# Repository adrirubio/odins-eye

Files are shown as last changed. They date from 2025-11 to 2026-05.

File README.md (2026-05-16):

# Odin's Eye

**Full Design Process**: [Blueprint Project](https://blueprint.hackclub.com/projects/413)

A compact speed detection system using a Raspberry Pi and a TF-Luna LiDAR sensor monitors vehicles in real time. When a vehicle is detected passing by, the system measures its speed and triggers the Raspberry Pi Camera Module 3 to capture an image.

Captured images are processed locally on a Raspberry Pi Zero 2 W, where the system identifies the vehicle and, when applicable, extracts license plate information. With built-in Wi-Fi connectivity, the unit wirelessly transmits speed data and image results directly to your phone. The entire system is designed to operate autonomously, combining precise sensing, on-device image analysis, and seamless wireless communication in a compact DIY build.

## Features

- **Vehicle Speed Detection:** Real-time speed measurement using a TF-Luna LiDAR sensor
- **Automatic Photo Capture:** Raspberry Pi Camera Module 3 captures an image when a vehicle passes
- **On-Device Processing:** Raspberry Pi Zero 2 W analyzes captured images locally
- **Vehicle Recognition:** Detects vehicles within the captured image
- **License Plate Detection:** Extracts license plate information when a car is detected
- **Wireless Notifications:** Sends captured data and images directly to your phone over WiFi
- **OLED Display:** Shows detected speed and system status directly on the device
- **Autonomous Operation:** Runs continuously without manual interaction
- **Compact DIY Design:** Designed as a small, self-contained monitoring system

## Hardware/BOM

| Component | Qty | Type |
|---|-----|---|
| Raspberry Pi Zero 2 W | 1 | Controller |
| Raspberry Pi Camera Module 3 | 1 | Camera Module |
| TF-Luna LiDAR Sensor | 1 | LiDAR Sensor |
| 0.95-inch OLED Display | 1 | Display |
| MPU6050 IMU | 1 | Sensor |
| microSD Card (32GB) | 1 | Storage |
| Custom Carrier PCB | 1 | PCB |
| Custom 3D Printed Case | 1 | Enclosure |
| Power Bank | 1 | Power |
| USB-A to USB-C Cable | 1 | Cable |
| Universal Tripod | 1 | Mount |
| Green LED Power Indicator | 1 | Indicator |
| Mounting Hardware (Assorted Screws) | 1 | Hardware |

## CAD Screenshots

| CAD Assembly (Front View)| CAD Assembly (Back View) |
|---|---|
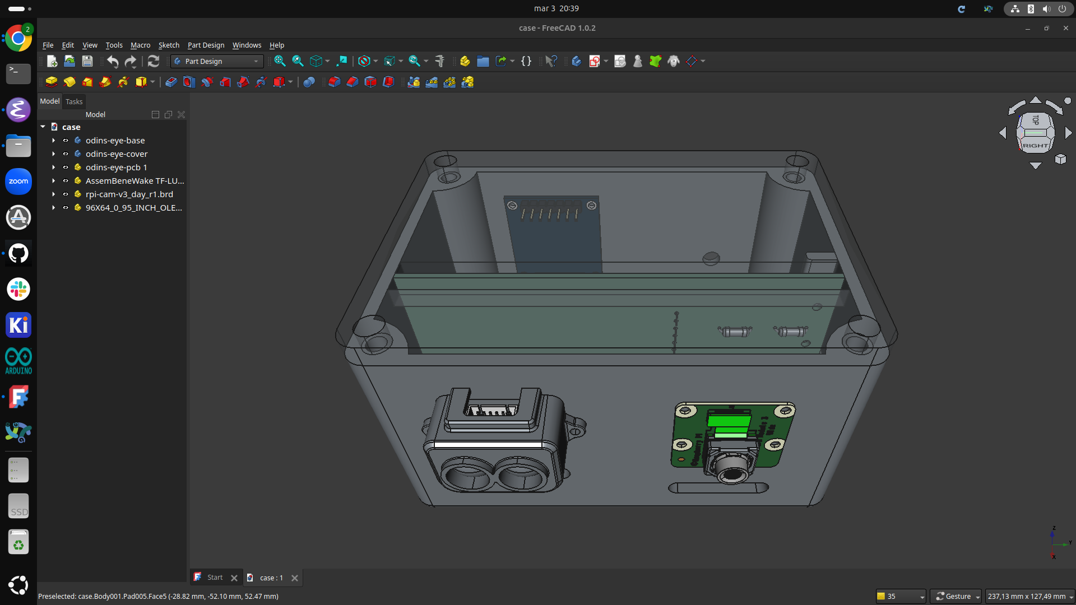
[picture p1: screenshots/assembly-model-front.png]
Assembly Model Front
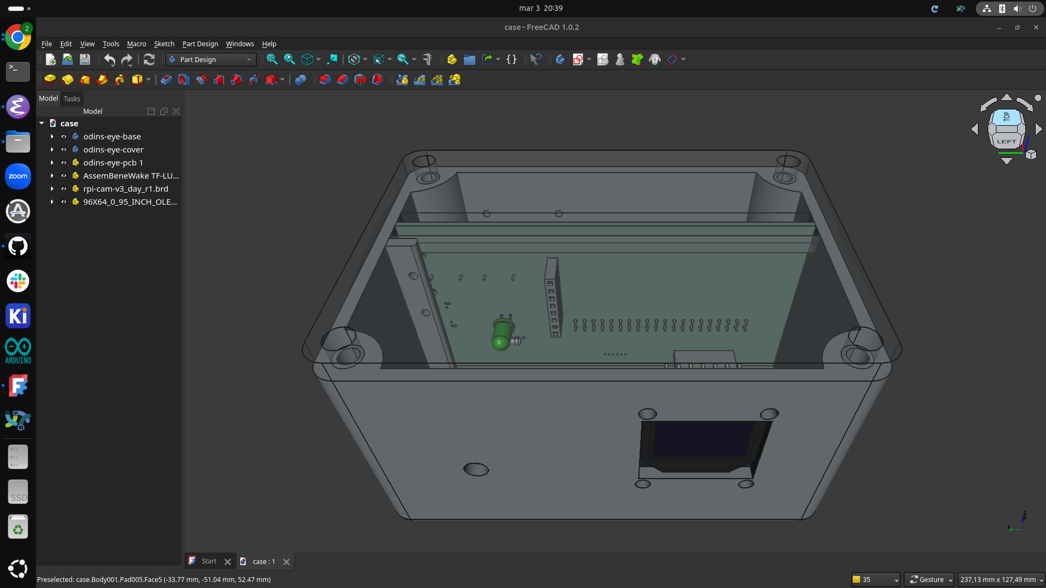
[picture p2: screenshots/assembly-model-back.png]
Assembly Model Back
|  |  |

| 3D Case (Side View) | 3D Case (Side View) |
|---|---|
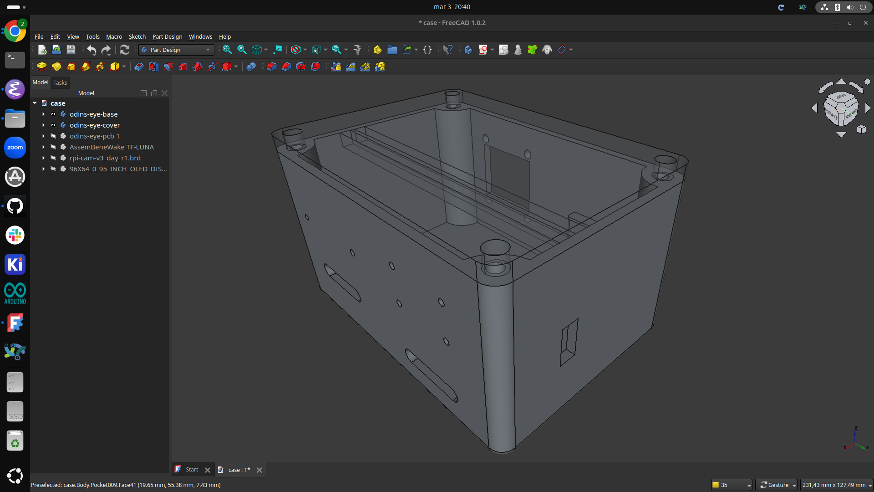
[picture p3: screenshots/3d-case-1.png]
3D Case Side
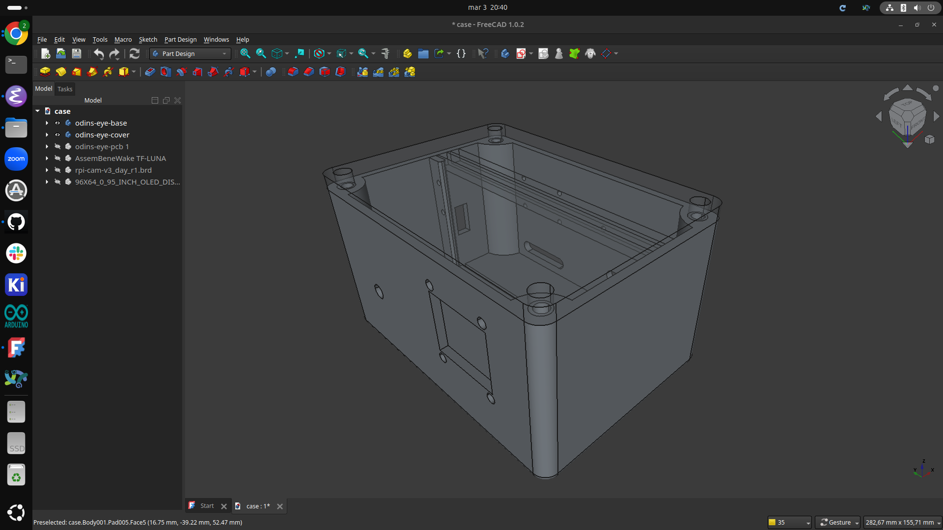
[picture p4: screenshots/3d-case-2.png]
3D Case Side
|  |  |

## PCB Screenshots

| PCB Layout |
|-------------------------------|
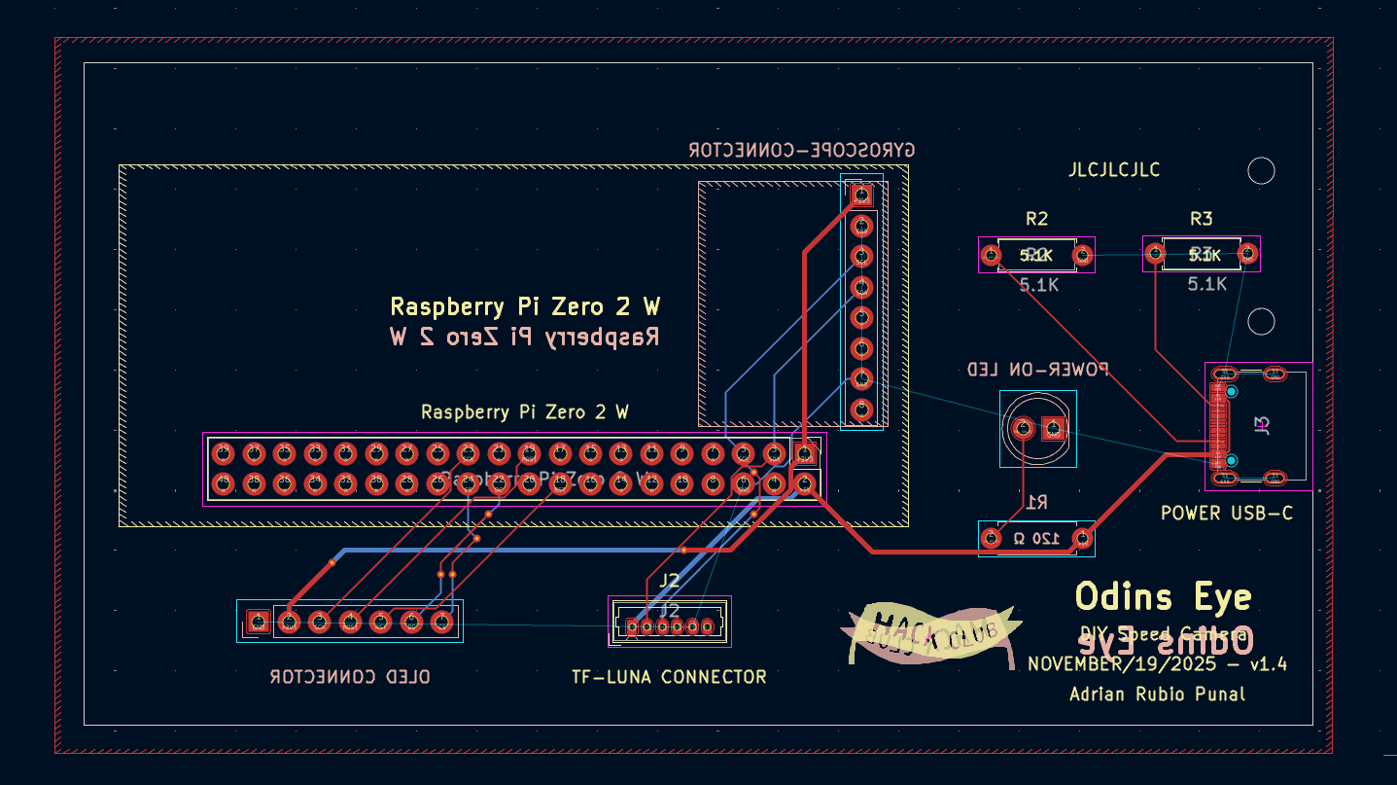
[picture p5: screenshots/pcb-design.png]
PCB Layout
|  |

| PCB 3D View (Front) | PCB 3D View (Back) |
|---|---|
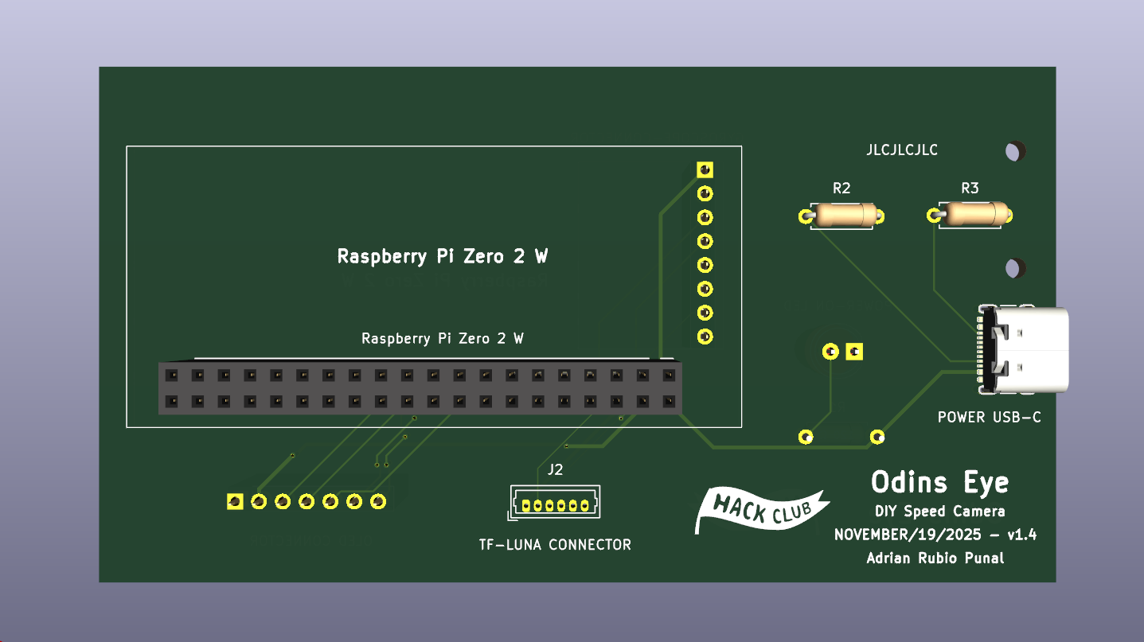
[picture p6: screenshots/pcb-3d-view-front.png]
PCB 3D View (Front)
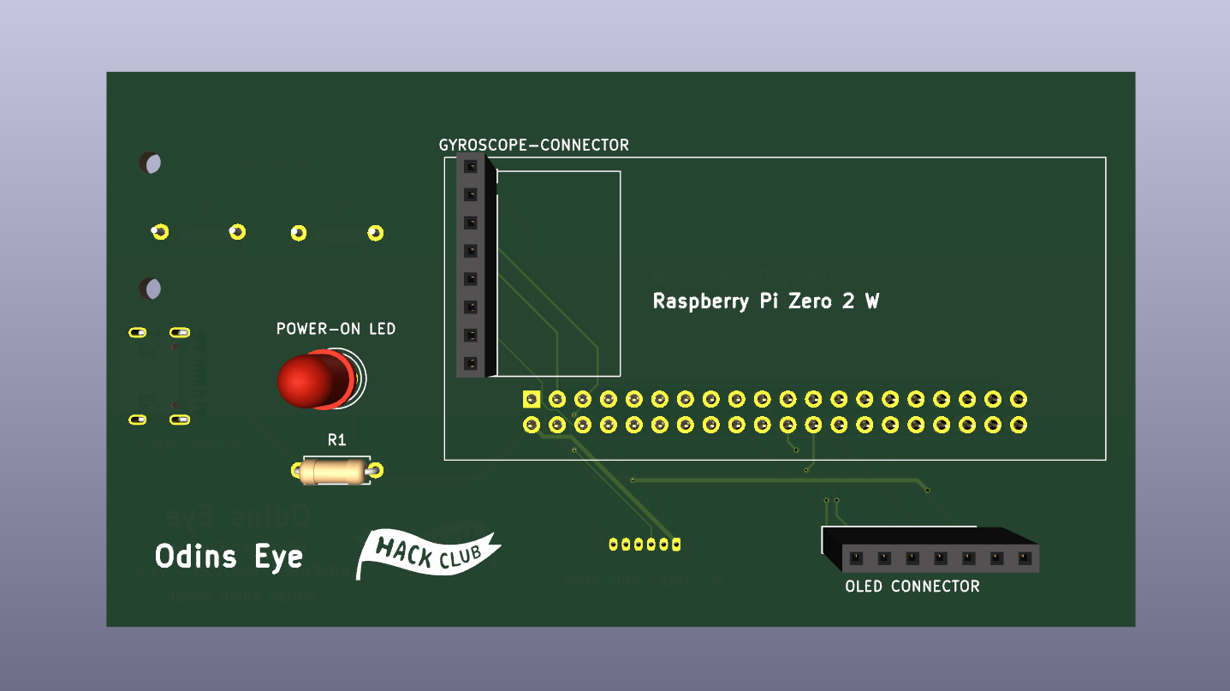
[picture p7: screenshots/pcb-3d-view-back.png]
PCB 3D View (Back)
|  |  |

## Usage
Place the system facing the road and use the built-in gyroscope to help align the device at the correct angle for accurate measurements. The TF-Luna LiDAR sensor detects passing vehicles and calculates their speed, triggering the camera to capture an image as a vehicle passes. The Raspberry Pi then processes the image to detect the vehicle and extract the license plate if possible, sending the results to your phone over WiFi. The detected speed and system status are also displayed on the integrated OLED screen, allowing you to quickly view results directly on the device.

## Odins Eye In Action

| Complete Assembly |
|-------------------------------|
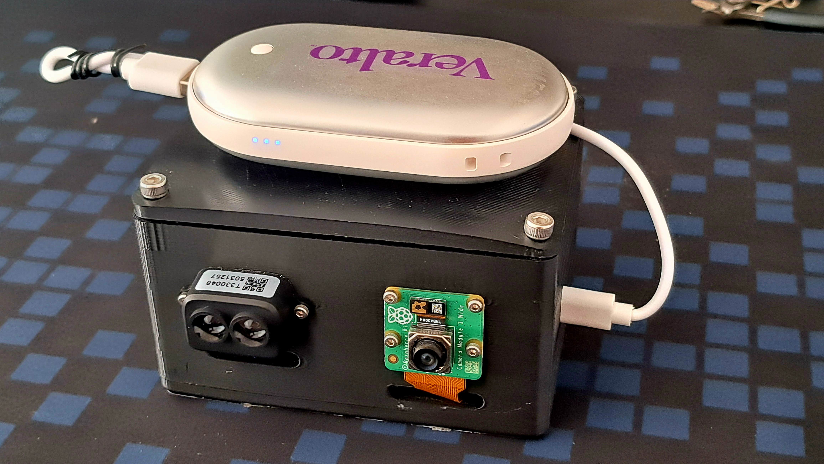
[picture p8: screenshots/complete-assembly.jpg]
Complete Assembly
|  |

| Complete Assembly (Front View)| Complete Assembly (Front View) |
|---|---|
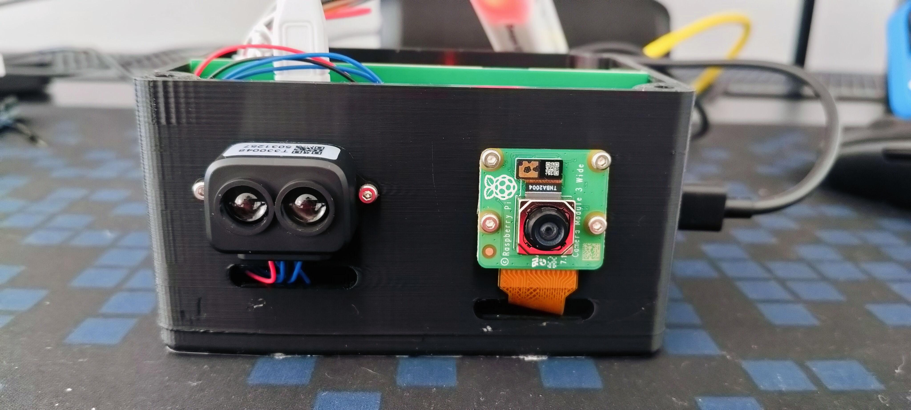
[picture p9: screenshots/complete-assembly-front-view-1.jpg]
Complete Assembly Front View
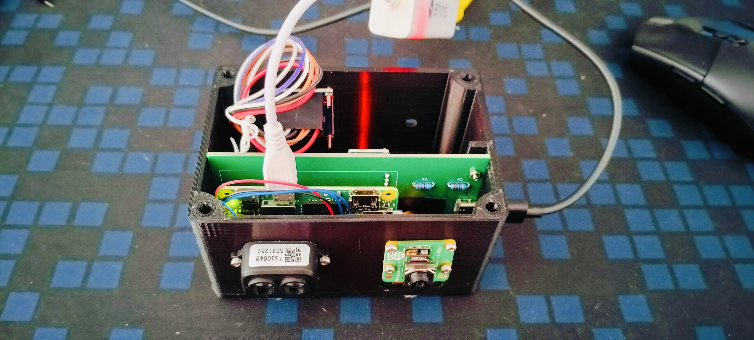
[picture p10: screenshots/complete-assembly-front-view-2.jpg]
Complete Assembly Front View
|  |  |

| Complete Assembly (Top View)| Complete Assembly (Side View) |
|---|---|
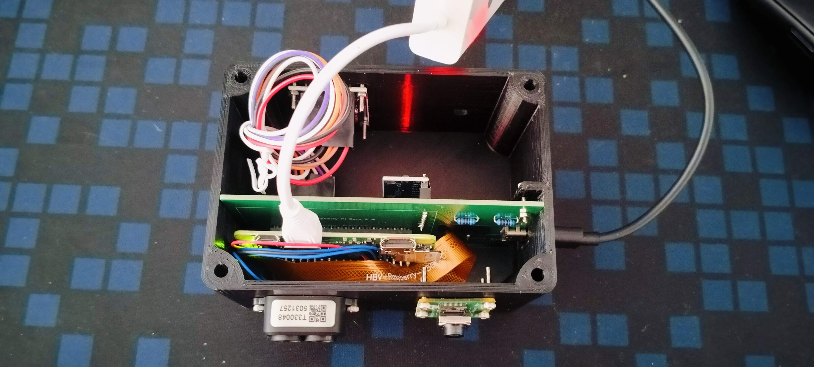
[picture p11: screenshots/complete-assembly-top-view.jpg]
Complete Assembly Top View
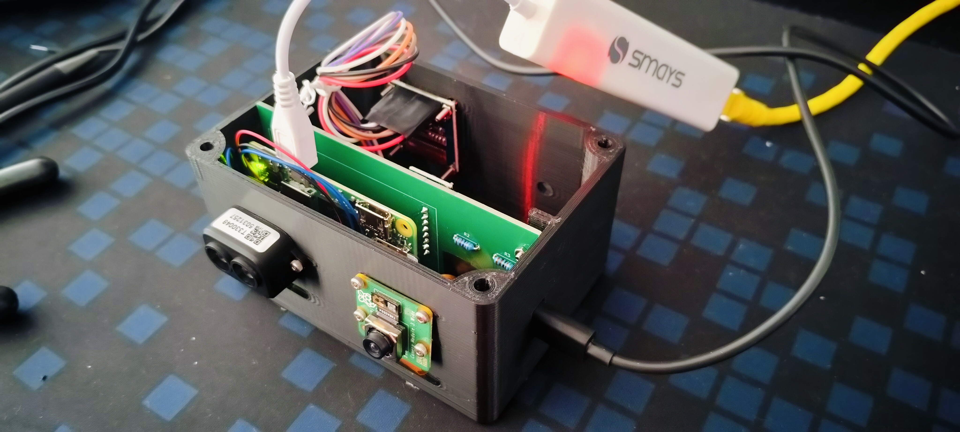
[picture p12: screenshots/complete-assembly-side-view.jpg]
Complete Assembly Side View
|  |  |

| Complete Assembly (Back View)| Complete Assembly (Back View) |
|---|---|
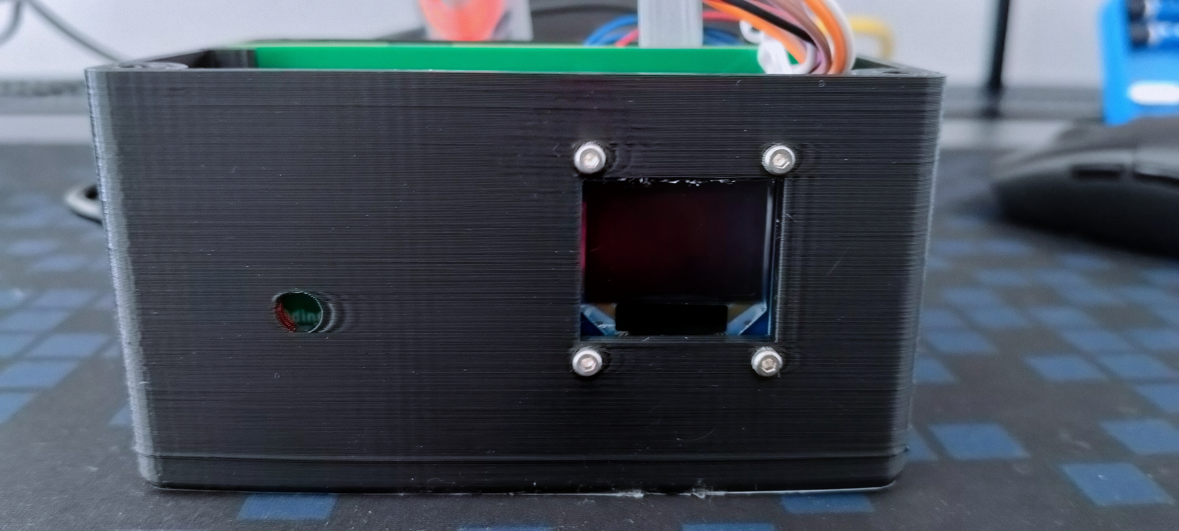
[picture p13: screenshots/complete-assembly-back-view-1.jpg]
Complete Assembly Back View
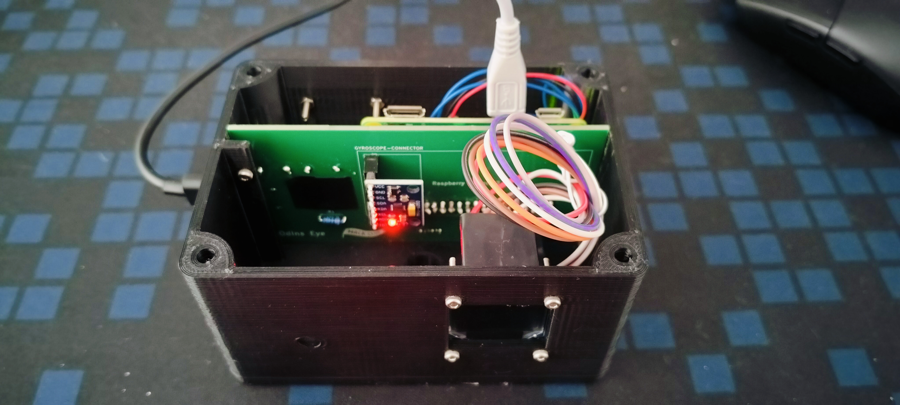
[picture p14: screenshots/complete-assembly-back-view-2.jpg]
Complete Assembly Back View
|  |  |

### Odins Eye Demo
<a href="https://github.com/adrirubio/odins-eye/raw/main/demo/video/odins-eye-demo.mp4">Click here to download the demo video (MP4)</a>

### YouTube Demo
[Watch the demo on YouTube](https://youtu.be/cNV2ZcgS8Qw)

## Running on the Pi

The firmware lives in `firmware/`. Two entry points:

- `odins_eye_speed_monitor.py` — the live detector (TF-Luna sampling, gyro calibration, camera trigger, capture metadata).
- `odins_eye_dashboard_server.py` — a small HTTP server that serves the latest captures at `http://<pi-ip>:8080`.

### One-time setup on the Pi

```bash
sudo apt install python3-pil python3-smbus2 rpicam-apps
git clone https://github.com/adrirubio/odins-eye.git ~/Documents/odins-eye
sudo bash ~/Documents/odins-eye/firmware/systemd/install.sh
```

The install script copies the systemd units into `/etc/systemd/system/`, enables them, and starts both services. After a reboot, both come up automatically.

### Manual run for roadside testing

When you want the gyro calibration prompt and live burst logs in your terminal:

```bash
sudo systemctl stop odins-eye-detector
bash ~/Documents/odins-eye/firmware/odins_eye_start.sh
```

Ctrl-C stops both detector and dashboard. To return to autostart mode:

```bash
sudo systemctl start odins-eye-detector
```

### Useful commands

```bash
systemctl status odins-eye-detector
systemctl status odins-eye-dashboard
journalctl -u odins-eye-detector -f          # live detector log
journalctl -u odins-eye-dashboard -f         # live dashboard log
```

## License

MIT License

---

> GitHub [@adrirubio](https://github.com/adrirubio) &nbsp;&middot;&nbsp;

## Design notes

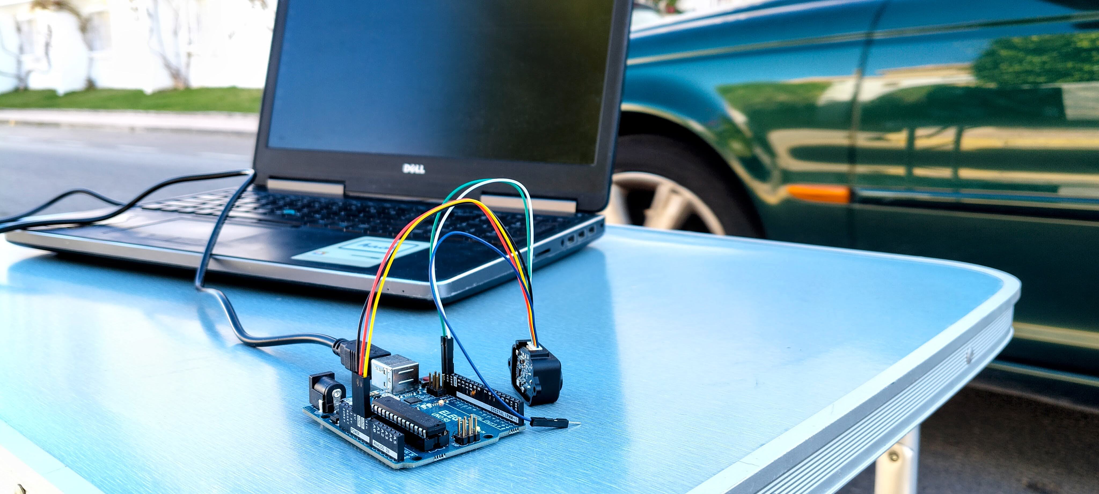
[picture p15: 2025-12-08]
demo/POC-pictures/POC3.jpg

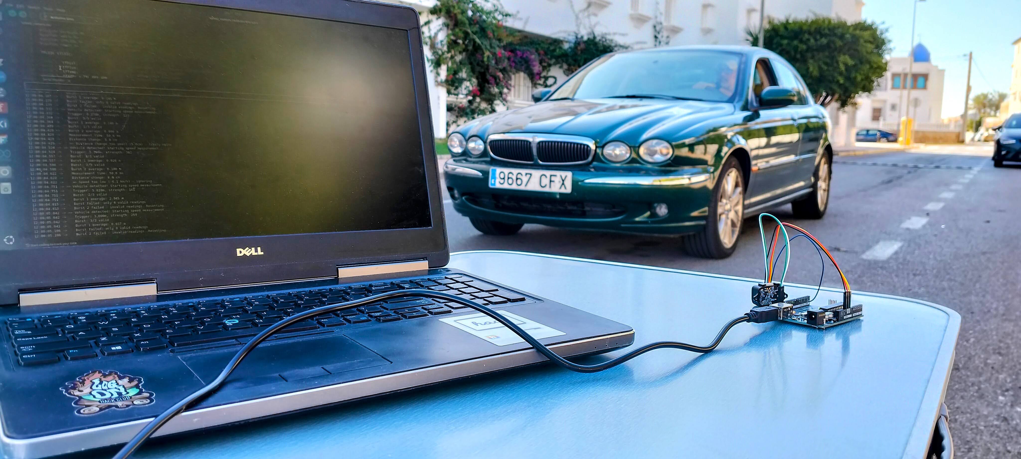
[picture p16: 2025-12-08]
demo/POC-pictures/POC2.jpg

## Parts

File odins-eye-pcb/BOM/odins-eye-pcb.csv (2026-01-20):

Comment | Designator | Footprint | LCSC Part Number
USB Type-C Receptacle, USB 2.0, Right-Angle, Top-Mount, SMT, TH Shell Stakes, 5A 48V | J3 | USB_C_Receptacle_GCT_USB4105-xx-A_16P_TopMnt_Horizontal | C3020560

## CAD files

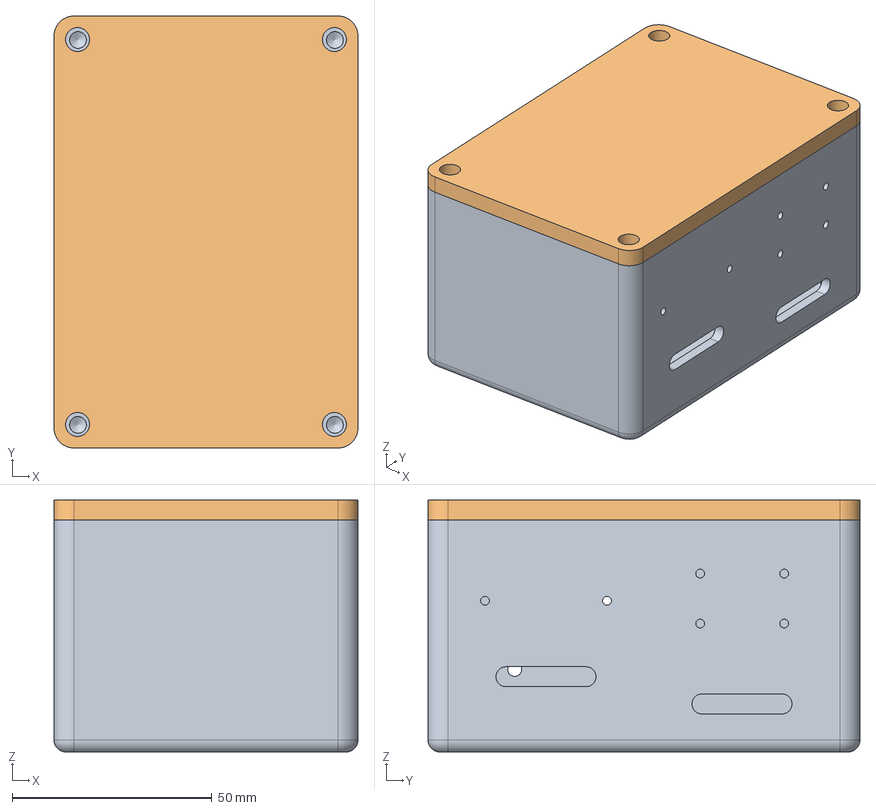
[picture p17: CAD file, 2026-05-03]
odins-eye-case/case.FCStd
76.0 x 108.0 x 63.0 mm
odins-eye-base
odins-eye-cover

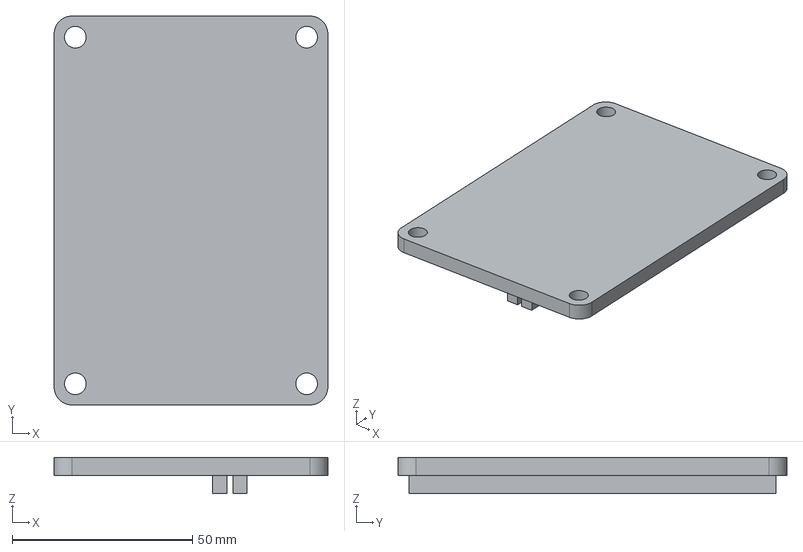
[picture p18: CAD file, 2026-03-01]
odins-eye-case/STEP-files/case-odins-eye-cover.step
76.0 x 108.0 x 10.0 mm

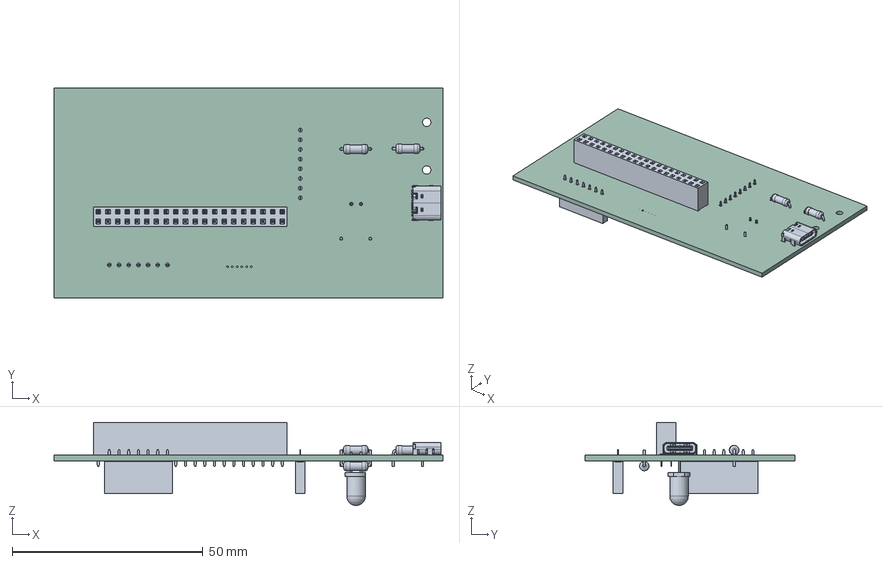
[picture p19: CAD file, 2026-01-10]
odins-eye-pcb/odins-eye-pcb/odins-eye-pcb.step
102.0 x 55.0 x 21.8 mm
USB_C_Receptacle_GCT_USB4105-xx-A_16P_TopMnt_Horizontal
R_Axial_DIN0207_L6.3mm_D2.5mm_P7.62mm_Horizontal x 3
PinSocket_2x20_P2.54mm_Vertical
PinSocket_1x08_P2.54mm_Vertical
LED_D5.0mm
PinSocket_1x07_P2.54mm_Vertical
odins-eye-pcb_PCB

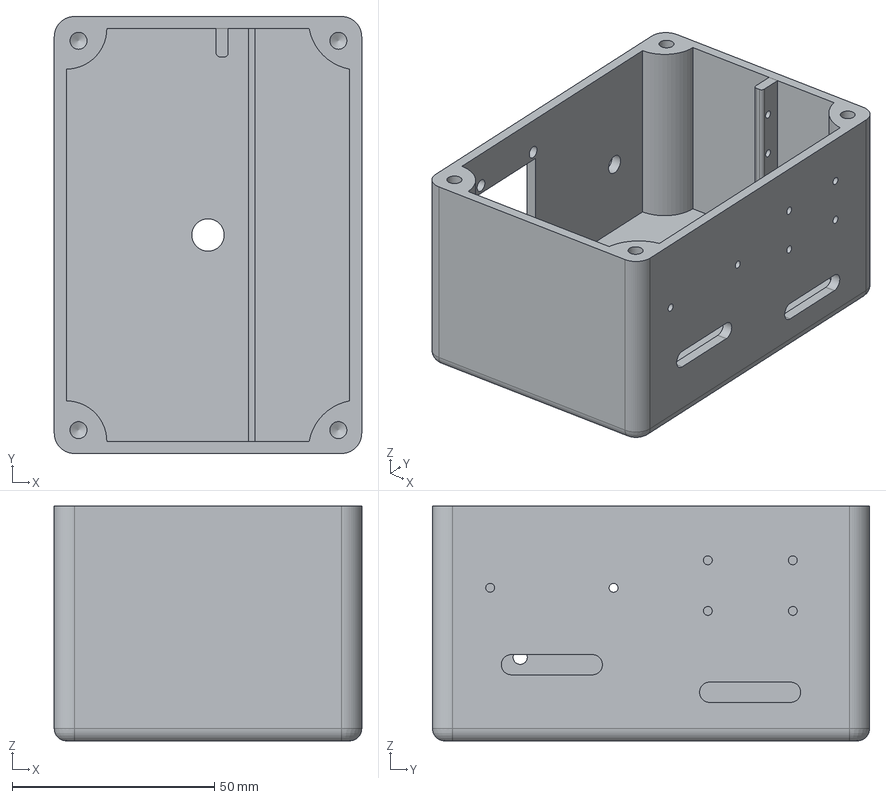
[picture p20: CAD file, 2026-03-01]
odins-eye-case/STEP-files/case-odins-eye-base.step
76.0 x 108.0 x 58.0 mm

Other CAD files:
odins-eye-case/STL-files/enclosure-cover.stl
odins-eye-case/STL-files/enclosure-base.stl

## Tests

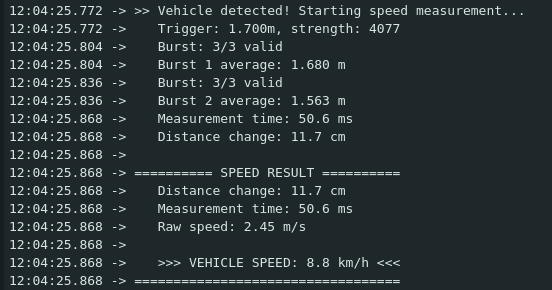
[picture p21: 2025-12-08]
demo/POC-pictures/results.png

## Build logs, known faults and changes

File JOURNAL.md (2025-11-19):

<!--
  ===================    !!READ THIS NOTICE!!   ====================
  DO NOT edit this file manually. Your changes WILL BE OVERWRITTEN!
  This journal is auto generated and updated by Hack Club Blueprint.
  To edit this file, please edit your journal entries on Blueprint.
  ==================================================================
-->

## 10/12/2025 - Research and Project BOM  

I started brainstorming how a DIY speed camera could be possible 3 days ago, and I am quite content with the basic idea I have after a few hours of project and parts research. My original idea was for the speed camera to have a stand that can rotate and follow vehicles while they pass, but I quickly realized that this would overcomplicate the project too much because I would have to design a stand from scratch. I settled for a universal stand where the speed camera and sensor are inside a 3d-printed case that screws onto it. I also wanted a touch screen where you could do some sort of onboarding every time you turned the speed camera on, but this idea was also quickly discarded because the onboarding would be unnecessary and small oled displays usually don't have touch capabilities. I needed the project to be standalone because my idea was for it to be in front of my house and gather data from the passing vehicles. I thought that having a battery holder and a slide switch to turn on was a good idea, but, after talking it over with my dad we decided that it was a better idea to have a power bank that would connect to the pcb/carrier board inside the case through a type-c plug.  

After lots of research and modifying the design several times I ended up with the following base idea that I will build on top of:

The system is controlled by a raspi zero 2w that has a raspi camera module 3, a TF-Luna lidar, and a small, possibly 0,95 inch oled display connected. It works by detecting a vehicle before it passes using the lidar which triggers the camera module 3 to start recording. From the recording it can get the speed using the frames-per-second and distance, it understands using AI what object passed and in the case of it being a car, its license plate. It'll get power from a power bank that can be mounted on top of the 3d-printed case. The lidar and camera will be situated on the front side of the 3d-printed case and on the back will be the oled display and a small green LED that turns on when the pcb/carrier board gets power. Lastly, using the pi's wifi it can send notifications to my phone.

I made the project BOM which you can check out in here: https://github.com/adrirubio/odins-eye/blob/main/bom.csv. I also made some rough sketches with the base idea I have up until now, but none of these are permanent.

Messy Iteration:


Complete Design:


PCB/Carrier Board:
  

## 10/21/2025 - Updated Speed Measurement Method  

I realize that measuring the speed of a vehicle from a video is extremely difficult. There are so many variables that come into play. Now I see how silly my idea was. Here are some of the things that make my original idea so challenging:

- You need to know the real-world distance the car actually travelled
- The video's timing is often unreliable because the frame rate isn't constant
- The camera's angle and lens bend the image

So... I decided to have a long chat with Gemini about other options. I looked into the doppler radar but realized that for it to work I would also need an amplifier, a sperate analog circuit, because the signal would be too weak and noisy for the raspi to read directly. I also looked at the microwave motion sensor but that didn't work because it would detect 360 degrees, so it would also trigger objects moving behind it.

More Messy Iteration:


Then I had a eureka moment; I realized that maybe we could somehow use the TF-Luna lidar to measure the speed of vehicles. Very soon I realized that this could work, here are some reasons why:

- It uses a narrow laser beam, so it will only detect cars passing in front of it
- It's electronically simple, you can connect it directly to the raspi's GPIO pins (via I2C)
- It has very low power consumption and won't put any strain on the power bank (much more efficient than the camera-only method)
- It's extremely fast, at 100Hz, the sensor can check the distance 100 times per second
- It's very compact and it was already in the original design

https://www.amazon.es/-/en/Benewake-TF-Luna-Compatible-Pixhawk-Raspberry/dp/B0DKCSF8C5

Now I would like to briefly explain what a lidar is and what it does. A lidar works by shooting a tiny beam of light and measuring exactly how long it takes for that light to bounce off an object and return.

My first idea on how to get speed was to use the Pythagorean theorem, to use it there would be one fixed distance in the code (a) the perpendicular distance to the side of the road, and we would use the lidar to measure the diagonal distance to the car (c). Using the Pythagorean theorem we would solve for the car's true position along the road (b = sqrt(c^2 - a^2)). By taking two of these measurements in say 0.1 seconds, we could determine the distance the car travelled and divide by the time to find the speed.

The only problem with this method is that it wouldn't be fully drop-and-go because you would have to make sure that (a) is the same in the code as in real life and if not change one of the two. What I am looking for is a completely stand-alone speed camera that starts working without having to be placed at any specific distance.

Knowing this I looked into some other options and found a very promising one; the least squares fit option. In this one the lidar is placed facing the road at roughly 45-degrees angle (I plan on designing a lock on the case). The lidar sends a distance reading every 0.1s until it detects an object in its path, once this happens it starts sending distance readings every 0.001 or 0.005 (I haven't decided yet) and because the object is getting closer at an angle, the distance will decrease as long as the lidar isn't hitting the side of the vehicle. Then it fits a straight line through the readings. The slope of that line tells how fast the distance is shrinking. Because the sensor is tilted, it divides that slope by cos(θ) to get the real speed of the object moving across its view.

To prove this concept, I built some simple example code in python (which I might have to replicate in C++ if speed is a problem) to test the basic idea. I would ask chatgpt to generate a set of distances and the corresponding signal strength and I would test it, honestly I think this might actually work:





Code:
https://github.com/adrirubio/odins-eye/blob/main/firmware/speed-calculation-code.py

To see how this works I bought a TF-Luna lidar to try both of these methods out. It still hasn't arrived but when it does I plan on seeing which of the two speed measurement methods works better and do a proof of concept.  

## 11/5/2025 - Starting The Schematic  

The TF Luna arrived, but because of an ordering mistake, it didn't have the right cables so I couldn't connect it to the breadboard. I could buy the cable separately, but I found one that has all the right cables and is quite cheap, so I decided to buy it. Unfortunately, it will take around two weeks to arrive, so I decided to get started with the schematics.

TF Luna: https://www.amazon.com/Wishiot-TF-Luna-Single-Point-Terminal-WiFi_Lora_32/dp/B09PZ559ZB

This is my first time designing schematics, so to begin with, I looked at some of the guides Blueprint offers. I began by trying EasyEDA. Created an account, started the project, and got a better idea of what components I needed. I started inserting some of the components into EasyEDA. At this point, I needed to get the basics down so I looked at some tutorials. One that helped a lot was this one: https://www.youtube.com/watch?v=R_Ud-FxUw0g

After these tutorials, I thought that I might also have a look at KiCad, so I downloaded it, created the odins-eye project, and having a better idea of what I was doing, I started to get a good feel for it. After following this tutorial for a bit: https://docs.kicad.org/6.0/en/getting_started_in_kicad/getting_started_in_kicad.html, I decided that I was ready to begin designing the speed camera.

The first thing that I looked at was the raspi's 40 GPIO pin header (2x20). Because there wasn't the exact model I needed, and also because I needed to get familiar with KiCad, I decided to design my own. Which I am quite proud of.

Next, I inserted a 6-pin connector which represents the JST connector. I also added the USB-C plug, a 30-pin connector which represents the ZIF connector for the 0.96 oled, one LED with a corresponding resistor, and two more resistors for a voltage divider to measure the battery.

This is where I’m up to so far:

kicad2

## 11/9/2025 - Wiring the Schematic  

I started by laying out the different parts of the project, placing the inputs and power connections on the left, the processing in the middle, and the outputs on the right. This setup made it easier to visualize how data and power would flow through the system. Before wiring the sections, I spent some time researching and watching a few tutorials to make sure I understood everything. I also looked at a few example schematics to double-check pin configurations.

For the plug, I found that I would actually need a USB-C receptacle because I just needed it for charging the circuit. I only connected the necessary power and ground pins and included the proper CC resistors for charging negotiation, then moved on to the 6-pin connector.
The 6-pin connector was fairly easy because, using the pinout diagram from the TF-Luna we had bought, I connected 5V, RXD, TXD, and GND. The last two pins aren't used in this model.

At this point, I connected 5V, GND, RXD, and TXD to pins 2, 6, 8, and 10 respectively on the raspi's GPIO header. I moved on to the 30-pin connector, and here I had some problems. I originally wanted this 30-pin connector because it has no extra PCB border and is great for custom enclosures. The problem is I would have to connect around 20–25 of the 30 pins.

30-pin-connector

I would also have to add capacitors with different values and deal with a large number of pins. This is highly error-prone, and iteration with hardware isn't quick. In the end, I decided to delete the 30-pin connector and use the 7-pin connector, which would represent a header for an OLED like this:
https://www.amazon.es/-/en/HiLetgo-SSD1331-Display-3-3V-5V-Colorful/dp/B0813BB3K7

I wired this 7-pin connector and, lastly, wired the LED, which I decided would be green, using a 1 kΩ resistor. Once everything was wired, I added some no-connect flags on a few unused pins, and a small note on the USB-C. I finished by fixing two or three warnings from the ERC.

schematic2schematic

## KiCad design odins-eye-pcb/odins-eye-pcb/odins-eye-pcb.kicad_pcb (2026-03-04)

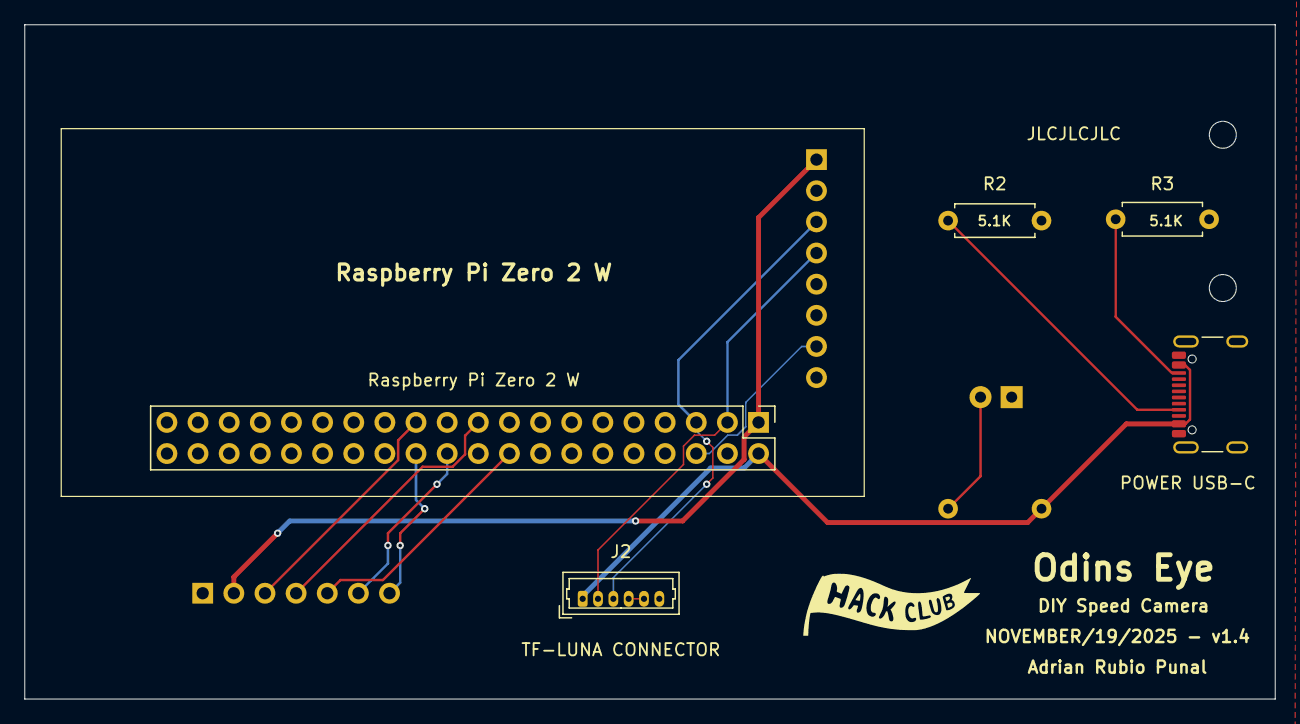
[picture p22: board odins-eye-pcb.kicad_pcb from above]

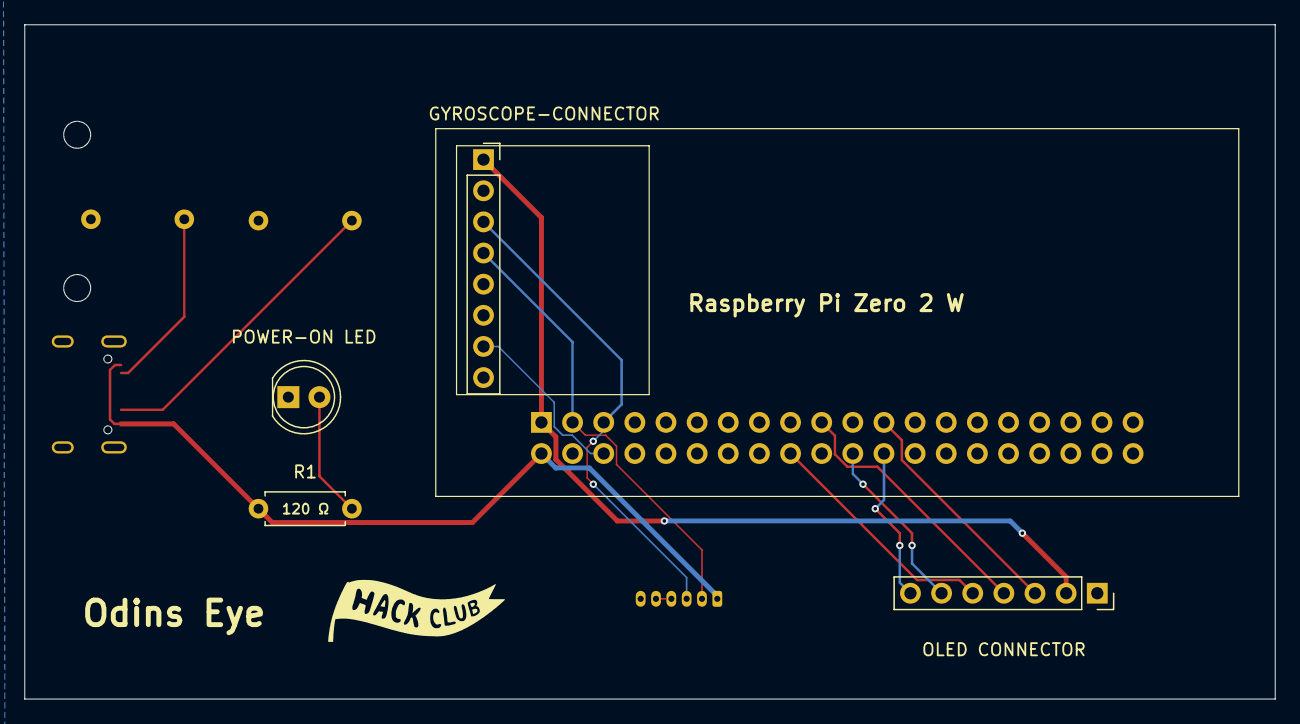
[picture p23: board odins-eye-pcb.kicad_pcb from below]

Board: 4 copper layers, 102.0 x 55.0 mm, 9 parts (4 on the bottom side), 13 nets.

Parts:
J2: TF-LUNA CONNECTOR; Molex_PicoBlade_53047-0610_1x06_P1.25mm_Vertical
J3: POWER USB-C; USB_C_Receptacle_GCT_USB4105-xx-A_16P_TopMnt_Horizontal
J4: GYROSCOPE-CONNECTOR; PinSocket_1x08_P2.54mm_Vertical
OLED CONNECTOR: Conn_01x07_Pin; PinSocket_1x07_P2.54mm_Vertical
POWER-ON LED: LED; LED_D5.0mm
R1: 120; R_Axial_DIN0207_L6.3mm_D2.5mm_P7.62mm_Horizontal
R2, R3: 5.1K; R_Axial_DIN0207_L6.3mm_D2.5mm_P7.62mm_Horizontal
Raspberry Pi Zero 2 W: Raspberry Pi Zero 2 W Header; PinSocket_2x20_P2.54mm_Vertical

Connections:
+3V3: J4.1, OLED CONNECTOR.2, Raspberry Pi Zero 2 W.1 (3V3)
+5V: J2.1, J3.A4 (VBUS), J3.A9 (VBUS), J3.B4 (VBUS), J3.B9 (VBUS), R1.1, Raspberry Pi Zero 2 W.2 (5V)
/CS: OLED CONNECTOR.7, Raspberry Pi Zero 2 W.24 (CE0)
/DC: OLED CONNECTOR.6, Raspberry Pi Zero 2 W.22 (GPIO25)
/MOSI: OLED CONNECTOR.4, Raspberry Pi Zero 2 W.19 (MOSI)
/RST: OLED CONNECTOR.5, Raspberry Pi Zero 2 W.18 (GPIO24)
/SCK: OLED CONNECTOR.3, Raspberry Pi Zero 2 W.23 (SCLK)
/SCL: J2.3, J4.3, Raspberry Pi Zero 2 W.5 (SCL1)
/SDA: J2.2, J4.4, Raspberry Pi Zero 2 W.3 (SDA1)
GND: J2.4, J2.5, J3.A1 (GND), J3.A12 (GND), J3.B1 (GND), J3.B12 (GND), J3.S1 (SHIELD), J4.2, J4.7, OLED CONNECTOR.1, POWER-ON LED.1 (K), R2.2, R3.2, Raspberry Pi Zero 2 W.6 (GND)
unnamed: POWER-ON LED.2 (A), R1.2
unnamed: J3.A5 (CC1), R2.1
unnamed: J3.B5 (CC2), R3.1

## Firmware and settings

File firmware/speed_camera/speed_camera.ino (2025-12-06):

#include <Arduino.h>
#include <Wire.h>        // Instantiate the Wire library
#include <TFLI2C.h>      // TFLuna-I2C Library v.0.1.1
#include <math.h>        // For cos() function

TFLI2C tflI2C;

int16_t  tfDist;                        // Distance in centimeters (library output)
int16_t  tfFlux;                        // Signal strength (0-65535)
int16_t  tfTemp;                        // Temperature (not used)
int16_t  tfAddr = TFL_DEF_ADR;          // Default I2C address for TF-Luna

// ======================= CONFIGURATION =======================
const float ANGLE_DEGREES = 20.0;       // Angle of camera facing the road (degrees)
const float COS_ANGLE = cos(ANGLE_DEGREES * PI / 180.0);  // Pre-calculated cosine

const float GAP_TIME_MS = 30.0;         // Gap between burst 1 and burst 2 (milliseconds) - SHORT for fast objects

const int BURST_SIZE = 3;               // Number of measurements per burst
const float BASELINE_TOLERANCE_CM = 10.0; // Tolerance for baseline comparison (cm)

// Detection lock timeout - prevents system from hanging
const unsigned long DETECTION_TIMEOUT_MS = 5000;  // 5 seconds

// Speed validation thresholds
const float MIN_DISTANCE_CHANGE_M = 0.05;  // Minimum distance change to be valid (5cm) - LOWERED for fast objects
const float MAX_DISTANCE_CHANGE_M = 3.0;   // Maximum distance change (3m - sanity check)
const float MIN_SPEED_KMH = 5.0;           // Reject speeds below 5 km/h (probably noise/walking)
const float MAX_SPEED_KMH = 200.0;         // Reject speeds above 200 km/h (probably error)

// Signal strength threshold
const int MIN_SIGNAL_STRENGTH = 20;        // Minimum flux value for valid reading - LOWERED for distant objects

// Debug mode - set to true for detailed diagnostics
const bool DEBUG_MODE = true;

// Baseline distance - set to 0 if no wall within range, otherwise the wall distance
float baselineDistance = 0.0;           // Will be calibrated on startup (in meters)
bool baselineSet = false;

// Detection lock - prevents multiple readings of same vehicle
bool detectionLocked = false;           // True after a vehicle is detected, until baseline restored
unsigned long lockStartTime = 0;        // Time when lock started (for timeout)

// ======================= FUNCTION DECLARATIONS =======================
bool takeSingleReading(float &distance, int &strength);
float takeBurstAverage(unsigned long &burstTime);
float filterAndAverage(float readings[], int count);
void calibrateBaseline();
float calculateSpeed(float startDist, float endDist, float timeSeconds);
bool isValidReading(float reading, int strength);
bool isTriggered(float reading);
bool isBaselineRestored(float reading);
bool isBaselineOpen();

// ======================= SETUP =======================
void setup() {
    Serial.begin(115200);
    Wire.begin();

    Serial.println(F("==================================="));
    Serial.println(F("DIY LIDAR SPEED CAMERA v2.0"));
    Serial.println(F("Burst-Gap-Burst Algorithm (Fixed)"));
    Serial.println(F("==================================="));
    Serial.println();

    if (DEBUG_MODE) {
        Serial.println(F("[DEBUG MODE ENABLED]"));
        Serial.println();
    }

    // Wait for TF-Luna to initialize
    delay(500);

    // Calibrate baseline distance
    calibrateBaseline();

    Serial.println();
    Serial.println(F("Speed camera ready. Monitoring for vehicles..."));
    Serial.println();
}

// ======================= MAIN LOOP =======================
void loop() {
    // Take a single reading to check current state
    float currentReading;
    int currentStrength;

    if (!takeSingleReading(currentReading, currentStrength)) {
        delay(10);
        return;  // Failed to get reading
    }

    // If detection is locked, check for timeout or baseline restoration
    if (detectionLocked) {
        unsigned long lockDuration = millis() - lockStartTime;

        // Check timeout
        if (lockDuration > DETECTION_TIMEOUT_MS) {
            if (DEBUG_MODE) {
                Serial.print(F(">> TIMEOUT: Lock released after "));
                Serial.print(lockDuration);
                Serial.println(F("ms"));
            }
            detectionLocked = false;
            Serial.println(F(">> Lock timeout. Ready for next vehicle."));
            Serial.println();
        }
        // Check baseline restoration
        else if (isBaselineRestored(currentReading)) {
            if (DEBUG_MODE) {
                Serial.print(F(">> Baseline restored after "));
                Serial.print(lockDuration);
                Serial.println(F("ms"));
            }
            detectionLocked = false;
            Serial.println(F(">> Baseline restored. Ready for next vehicle."));
            Serial.println();
        }

        delay(10);
        return;
    }

    // Check if we have a valid reading and if it's different from baseline (vehicle detected)
    if (isValidReading(currentReading, currentStrength) && isTriggered(currentReading)) {

        Serial.println(F(">> Vehicle detected! Starting speed measurement..."));
        if (DEBUG_MODE) {
            Serial.print(F("   Trigger: "));
            Serial.print(currentReading, 3);
            Serial.print(F("m, strength: "));
            Serial.println(currentStrength);
        }

        // ========== BURST 1 ==========
        unsigned long burst1Time;
        float burst1Average = takeBurstAverage(burst1Time);

        if (burst1Average < 0) {
            Serial.println(F("   Burst 1 failed - invalid readings. Resetting..."));
            delay(100);
            return;
        }

        Serial.print(F("   Burst 1 average: "));
        Serial.print(burst1Average, 3);
        Serial.println(F(" m"));

        // ========== GAP ==========
        unsigned long gapStart = micros();
        delay((unsigned long)GAP_TIME_MS);
        unsigned long gapEnd = micros();

        // ========== BURST 2 ==========
        unsigned long burst2Time;
        float burst2Average = takeBurstAverage(burst2Time);

        if (burst2Average < 0) {
            Serial.println(F("   Burst 2 failed - invalid readings. Resetting..."));
            delay(100);
            return;
        }

        Serial.print(F("   Burst 2 average: "));
        Serial.print(burst2Average, 3);
        Serial.println(F(" m"));

        // ========== CALCULATE ACTUAL TIME ELAPSED ==========
        // Time from middle of burst 1 to middle of burst 2
        unsigned long totalTime = (gapEnd - gapStart) + (burst1Time + burst2Time) / 2;
        float totalTimeSeconds = totalTime / 1000000.0;  // Convert microseconds to seconds

        if (DEBUG_MODE) {
            Serial.print(F("   Measurement time: "));
            Serial.print(totalTimeSeconds * 1000, 1);
            Serial.println(F(" ms"));
        }

        // ========== CALCULATE SPEED ==========
        float distanceChange = burst1Average - burst2Average;
        float absDistanceChange = fabs(distanceChange);

        if (DEBUG_MODE) {
            Serial.print(F("   Distance change: "));
            Serial.print(absDistanceChange * 100, 1);
            Serial.println(F(" cm"));
        }

        // Validate distance change magnitude
        if (absDistanceChange < MIN_DISTANCE_CHANGE_M) {
            Serial.print(F("   >> Distance change too small ("));
            Serial.print(absDistanceChange * 100, 1);
            Serial.println(F("cm) - likely noise"));
            delay(100);
            return;
        }

        if (absDistanceChange > MAX_DISTANCE_CHANGE_M) {
            Serial.print(F("   >> Distance change too large ("));
            Serial.print(absDistanceChange, 2);
            Serial.println(F("m) - likely error"));
            delay(100);
            return;
        }

        float speed = calculateSpeed(burst1Average, burst2Average, totalTimeSeconds);
        float speedKmh = speed * 3.6;

        // Validate speed range
        if (speedKmh < MIN_SPEED_KMH) {
            Serial.print(F("   >> Speed too low ("));
            Serial.print(speedKmh, 1);
            Serial.println(F(" km/h) - ignoring"));
            delay(100);
            return;
        }

        if (speedKmh > MAX_SPEED_KMH) {
            Serial.print(F("   >> Speed too high ("));
            Serial.print(speedKmh, 1);
            Serial.println(F(" km/h) - likely error"));
            delay(100);
            return;
        }

        // ========== VALID SPEED DETECTED ==========
        Serial.println();
        Serial.println(F("========== SPEED RESULT =========="));
        Serial.print(F("   Distance change: "));
        Serial.print(absDistanceChange * 100, 1);
        Serial.println(F(" cm"));
        Serial.print(F("   Measurement time: "));
        Serial.print(totalTimeSeconds * 1000, 1);
        Serial.println(F(" ms"));
        Serial.print(F("   Raw speed: "));
        Serial.print(speed, 2);
        Serial.println(F(" m/s"));
        Serial.println();
        Serial.print(F("   >>> VEHICLE SPEED: "));
        Serial.print(speedKmh, 1);
        Serial.println(F(" km/h <<<"));
        Serial.println(F("=================================="));
        Serial.println();

        // Lock detection until baseline is restored (vehicle has passed)
        detectionLocked = true;
        lockStartTime = millis();
        Serial.println(F(">> Detection locked. Waiting for vehicle to pass..."));
        if (DEBUG_MODE) {
            Serial.print(F("   Timeout in "));
            Serial.print(DETECTION_TIMEOUT_MS / 1000);
            Serial.println(F(" seconds"));
        }
    }

    // Small delay between monitoring readings
    delay(10);
}

// ======================= HELPER FUNCTIONS =======================

/**
 * Take a single distance reading from the TF-Luna
 * Returns true if successful, false otherwise
 * Outputs distance in meters and signal strength
 */
bool takeSingleReading(float &distance, int &strength) {
    if (tflI2C.getData(tfDist, tfFlux, tfTemp, tfAddr)) {
        // TF-Luna outputs distance in centimeters, convert to meters
        distance = tfDist / 100.0;
        strength = tfFlux;
        return true;
    }
    return false;
}

/**
 * Check if a reading is valid (positive distance and good signal strength)
 */
bool isValidReading(float reading, int strength) {
    if (reading <= 0) return false;
    if (strength < MIN_SIGNAL_STRENGTH) {
        if (DEBUG_MODE) {
            Serial.print(F("   Low signal: "));
            Serial.print(strength);
            Serial.print(F(" (min: "));
            Serial.print(MIN_SIGNAL_STRENGTH);
            Serial.println(F(")"));
        }
        return false;
    }
    return true;
}

/**
 * Check if baseline is effectively "no wall" (0 or very large)
 */
bool isBaselineOpen() {
    return (baselineDistance <= 0 || baselineDistance > 7.5);  // TF-Luna max range ~8m
}

/**
 * Check if a reading indicates a vehicle has entered the detection zone
 * Triggered when reading is significantly different from baseline
 */
bool isTriggered(float reading) {
    // If baseline is 0 or beyond range, any valid reading is a trigger
    if (isBaselineOpen()) {
        return (reading > 0.2 && reading < 8.0);  // Valid TF-Luna range
    }

    // Otherwise, trigger if reading is significantly closer than baseline
    float differenceFromBaseline = baselineDistance - reading;
    return (differenceFromBaseline > (BASELINE_TOLERANCE_CM / 100.0));
}

/**
 * Check if the baseline has been restored (vehicle has passed)
 * Returns true when reading is back to baseline (or no object detected for open baseline)
 */
bool isBaselineRestored(float reading) {
    // If baseline is open (no wall), restored when reading is 0 or beyond range
    if (isBaselineOpen()) {
        return (reading <= 0 || reading > 7.5);  // No object in range
    }

    // Otherwise, restored when reading is close to the original baseline
    float differenceFromBaseline = fabs(baselineDistance - reading);
    return (differenceFromBaseline <= (BASELINE_TOLERANCE_CM / 100.0));
}

/**
 * Take a burst of readings, filter outliers, and return the average
 * Also returns the time taken for the burst (in microseconds)
 * Returns -1 if not enough valid readings
 */
float takeBurstAverage(unsigned long &burstTime) {
    unsigned long startTime = micros();

    float readings[BURST_SIZE];
    int validCount = 0;

    // Take quick measurements
    for (int i = 0; i < BURST_SIZE; i++) {
        float reading;
        int strength;

        if (takeSingleReading(reading, strength) && isValidReading(reading, strength)) {
            readings[validCount] = reading;
            validCount++;
        }
        // Small delay between burst readings (TF-Luna can do up to 250Hz)
        delayMicroseconds(4000);  // ~4ms between readings for reliability
    }

    burstTime = micros() - startTime;

    if (validCount < 1) {
        if (DEBUG_MODE) {
            Serial.print(F("   Burst failed: only "));
            Serial.print(validCount);
            Serial.println(F(" valid readings"));
        }
        return -1.0;  // Not enough valid readings
    }

    if (DEBUG_MODE) {
        Serial.print(F("   Burst: "));
        Serial.print(validCount);
        Serial.print(F("/"));
        Serial.print(BURST_SIZE);
        Serial.println(F(" valid"));
    }

    return filterAndAverage(readings, validCount);
}

/**
 * Filter out outliers and return the average of remaining readings
 * Uses median-based outlier detection (more robust than voting)
 */
float filterAndAverage(float readings[], int count) {
    if (count == 0) return -1.0;
    if (count == 1) return readings[0];

    // Sort readings to find median
    for (int i = 0; i < count - 1; i++) {
        for (int j = 0; j < count - i - 1; j++) {
            if (readings[j] > readings[j + 1]) {
                float temp = readings[j];
                readings[j] = readings[j + 1];
                readings[j + 1] = temp;
            }
        }
    }

    // Use median for outlier detection
    float median = readings[count / 2];

    // Calculate MAD (Median Absolute Deviation)
    // First, compute absolute deviations from median
    float deviations[BURST_SIZE];
    for (int i = 0; i < count; i++) {
        deviations[i] = fabs(readings[i] - median);
    }

    // Sort deviations to find their median (the MAD)
    for (int i = 0; i < count - 1; i++) {
        for (int j = 0; j < count - i - 1; j++) {
            if (deviations[j] > deviations[j + 1]) {
                float temp = deviations[j];
                deviations[j] = deviations[j + 1];
                deviations[j + 1] = temp;
            }
        }
    }
    float mad = deviations[count / 2];

    // Remove outliers and calculate average
    float sum = 0;
    int validCount = 0;

    for (int i = 0; i < count; i++) {
        // Only remove if MAD is significant (> 2cm) and reading is far from median
        if (mad > 0.02 && fabs(readings[i] - median) > 2.5 * mad) {
            if (DEBUG_MODE) {
                Serial.print(F("      Outlier: "));
                Serial.print(readings[i], 3);
                Serial.println(F("m"));
            }
            continue;  // Skip this outlier
        }
        sum += readings[i];
        validCount++;
    }

    if (validCount == 0) {
        if (DEBUG_MODE) {
            Serial.println(F("   All readings filtered!"));
        }
        return -1.0;
    }

    return sum / validCount;
}

/**
 * Calculate the speed of the vehicle
 *
 * Formula: speed = (startDist - endDist) / time / cos(angle)
 *
 * The cosine correction accounts for the 20° angle of the sensor
 */
float calculateSpeed(float startDist, float endDist, float timeSeconds) {
    // Distance change (positive if vehicle approaching)
    float distanceChange = startDist - endDist;

    // Raw speed along the sensor's line of sight
    float rawSpeed = distanceChange / timeSeconds;

    // Apply cosine correction for the 20° angle
    // This gives us the actual speed along the road
    float correctedSpeed = rawSpeed / COS_ANGLE;

    return correctedSpeed;  // Can be negative if vehicle receding
}

/**
 * Calibrate the baseline distance on startup
 * Takes multiple readings and averages them to establish the baseline
 */
void calibrateBaseline() {
    Serial.println(F("Calibrating baseline distance..."));
    Serial.println(F("(Make sure the road is clear of vehicles)"));

    float sum = 0;
    int validReadings = 0;
    const int CALIBRATION_SAMPLES = 10;

    for (int i = 0; i < CALIBRATION_SAMPLES; i++) {
        float reading;
        int strength;

        if (takeSingleReading(reading, strength) && reading > 0) {
            sum += reading;
            validReadings++;
            Serial.print(F("  Sample "));
            Serial.print(i + 1);
            Serial.print(F(": "));
            Serial.print(reading, 3);
            Serial.print(F(" m (strength: "));
            Serial.print(strength);
            Serial.println(F(")"));
        }
        delay(100);
    }

    if (validReadings > 0) {
        baselineDistance = sum / validReadings;
        baselineSet = true;

        Serial.println();
        Serial.print(F("Baseline distance set to: "));
        Serial.print(baselineDistance, 3);
        Serial.println(F(" m"));

        // If baseline is 0 or beyond TF-Luna range, note this
        if (isBaselineOpen()) {
            Serial.println(F("(No wall detected - baseline is open/infinite)"));
            baselineDistance = 0;  // Set to 0 for open baseline
        }
    } else {
        Serial.println(F("WARNING: Could not establish baseline!"));
        Serial.println(F("Proceeding with baseline = 0 (open)"));
        baselineDistance = 0;
        baselineSet = true;
    }
}

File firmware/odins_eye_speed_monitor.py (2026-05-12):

#!/usr/bin/env python3

import argparse
import json
import math
import os
import subprocess
import time
from datetime import datetime

from PIL import Image, ImageDraw, ImageFont

from odins_eye_oled_bringup import HEIGHT, WIDTH, SSD1331


ANGLE_DEG = 45.0
COS_TH = math.cos(math.radians(ANGLE_DEG))
SAMPLE_INTERVAL = 0.010
MIN_STRENGTH = 35
MIN_DEC_SEQ = 3
MIN_TRIGGER_DROP_M = 0.08
MAX_BURST_TIME = 0.25
MIN_CHANGE = 0.15
SPEED_RANGE = (0.1, 60.0)
SPEED_SCALE = 0.67
DROP_FIRST_BURST_SAMPLE = True

TF_LUNA_ADDR = 0x10
IMU_ADDR = 0x68
TARGET_ALIGN_DEG = -20.0
ALIGN_TOLERANCE_DEG = 2.0
GYRO_Z_SCALE = 131.0

OLED_SPI_BUS = 0
OLED_SPI_DEVICE = 0
OLED_DC = 25
OLED_RST = 24

RAW_LOG_PATH = os.path.expanduser("~/odins-eye-captures/raw_events.jsonl")
CAPTURES_DIR = os.path.expanduser("~/odins-eye-captures")
CAMERA_TIMEOUT_MS = 200
CAMERA_WIDTH = 2304
CAMERA_HEIGHT = 1296


def parse_args() -> argparse.Namespace:
    parser = argparse.ArgumentParser(
        description="Live Pi-side speed detection using the repo's TF-Luna algorithm."
    )
    parser.add_argument("--bus", type=int, default=1, help="I2C bus number.")
    parser.add_argument(
        "--samples",
        type=int,
        default=0,
        help="Optional number of samples to read before exiting. 0 means run forever.",
    )
    parser.add_argument(
        "--show-raw",
        action="store_true",
        help="Print each raw sample while monitoring.",
    )
    parser.add_argument(
        "--skip-oled",
        action="store_true",
        help="Run without the OLED UI.",
    )
    parser.add_argument(
        "--skip-calibration",
        action="store_true",
        help="Skip startup gyro calibration; assume relative-zero alignment.",
    )
    parser.add_argument(
        "--raw-log",
        default=RAW_LOG_PATH,
        help="Path to append per-event raw traces (JSON lines).",
    )
    return parser.parse_args()


def open_bus(bus_number: int):
    try:
        from smbus2 import SMBus
    except ImportError:
        from smbus import SMBus
    return SMBus(bus_number)


def read_tfluna_sample(bus) -> tuple[float, int]:
    data = bus.read_i2c_block_data(TF_LUNA_ADDR, 0x00, 6)
    distance_cm = data[0] | (data[1] << 8)
    flux = data[2] | (data[3] << 8)
    return distance_cm / 100.0, flux


def read_imu_accel(bus) -> tuple[int, int, int]:
    raw = bus.read_i2c_block_data(IMU_ADDR, 0x3B, 6)
    values = []
    for index in range(0, 6, 2):
        value = (raw[index] << 8) | raw[index + 1]
        if value >= 0x8000:
            value -= 0x10000
        values.append(value)
    return values[0], values[1], values[2]


def read_imu_gyro(bus) -> tuple[int, int, int]:
    raw = bus.read_i2c_block_data(IMU_ADDR, 0x43, 6)
    values = []
    for index in range(0, 6, 2):
        value = (raw[index] << 8) | raw[index + 1]
        if value >= 0x8000:
            value -= 0x10000
        values.append(value)
    return values[0], values[1], values[2]


def compute_tilt_deg(ax: int, ay: int, az: int) -> float:
    return math.degrees(math.atan2(ax, math.sqrt((ay * ay) + (az * az))))


def fit_line(timestamps: list[float], readings: list[float]) -> tuple[float, float]:
    n = len(timestamps)
    centered_t = [t - (sum(timestamps) / n) for t in timestamps]
    mean_r = sum(readings) / n

    numerator = sum(t * (r - mean_r) for t, r in zip(centered_t, readings))
    denominator = sum(t * t for t in centered_t)
    slope = numerator / denominator if denominator else 0.0
    intercept = mean_r

    squared_error = 0.0
    for t, r in zip(centered_t, readings):
        predicted = (slope * t) + intercept
        squared_error += (r - predicted) ** 2
    err = math.sqrt(squared_error / n)
    return slope, err


def log_raw_event(path: str, event: dict) -> None:
    try:
        os.makedirs(os.path.dirname(path), exist_ok=True)
        with open(path, "a", encoding="ascii") as handle:
            handle.write(json.dumps(event) + "\n")
    except OSError as exc:
        print(f"raw log write failed: {exc}")


def score_confidence(
    sample_count: int,
    fit_err_cm: float,
    burst_drop_m: float,
    distances: list[float],
) -> tuple[int, str]:
    sample_score = min(1.0, max(0.0, (sample_count - 6) / 8.0))
    err_score = min(1.0, max(0.0, 1.0 - (fit_err_cm / 30.0)))
    drop_score = min(1.0, max(0.0, (burst_drop_m - 0.10) / 1.40))

    if len(distances) >= 2:
        decreasing = sum(
            1 for a, b in zip(distances, distances[1:]) if b <= a
        )
        monotonicity = decreasing / (len(distances) - 1)
    else:
        monotonicity = 0.0
    monotonicity_score = monotonicity

    weighted = (
        (sample_score * 0.20)
        + (err_score * 0.35)
        + (drop_score * 0.25)
        + (monotonicity_score * 0.20)
    )
    confidence_pct = int(round(weighted * 100))

    if confidence_pct >= 70:
        label = "high"
    elif confidence_pct >= 45:
        label = "medium"
    else:
        label = "low"

    return confidence_pct, label


_active_capture_proc: subprocess.Popen | None = None


def _reap_active_capture() -> None:
    global _active_capture_proc
    proc = _active_capture_proc
    if proc is None:
        return
    if proc.poll() is None:
        print(f"killing stale capture pid={proc.pid}")
        proc.kill()
        try:
            proc.wait(timeout=2)
        except subprocess.TimeoutExpired:
            pass
    _active_capture_proc = None


def start_capture(stem: str):
    global _active_capture_proc
    _reap_active_capture()
    os.makedirs(CAPTURES_DIR, exist_ok=True)
    image_path = os.path.join(CAPTURES_DIR, f"{stem}.jpg")
    command = [
        "rpicam-still",
        "-n",
        "-o", image_path,
        "--timeout", str(CAMERA_TIMEOUT_MS),
        "--width", str(CAMERA_WIDTH),
        "--height", str(CAMERA_HEIGHT),
    ]
    try:
        proc = subprocess.Popen(
            command,
            stdout=subprocess.DEVNULL,
            stderr=subprocess.DEVNULL,
        )
        _active_capture_proc = proc
        return proc, image_path
    except (OSError, FileNotFoundError) as exc:
        print(f"camera launch failed: {exc}")
        return None, ""


def write_capture_metadata(stem: str, payload: dict) -> str:
    metadata_path = os.path.join(CAPTURES_DIR, f"{stem}.json")
    try:
        os.makedirs(CAPTURES_DIR, exist_ok=True)
        with open(metadata_path, "w", encoding="ascii") as handle:
            json.dump(payload, handle, indent=2)
            handle.write("\n")
        return metadata_path
    except OSError as exc:
        print(f"metadata write failed: {exc}")
        return ""
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

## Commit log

2025-10-12 Initial bom.csv
    [bom.csv]
2025-11-19 Add KiCad files
    [odins-eye-pcb-B_Mask.gbs, odins-eye-pcb-B_Paste.gbp, odins-eye-pcb-B_Silkscreen.gbo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]
2025-11-27 Add odins-eye v1.1
    [odins-eye-pcb-B_Mask.gbs, odins-eye-pcb-B_Paste.gbp, odins-eye-pcb-B_Silkscreen.gbo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]
2025-12-06 Update arduino code
    [odins-eye-pcb.kicad_pcb]
2025-12-08 Project enclosure
    [case.FCStd]
2025-12-16 Update 3D printed case
    [odins-eye-pcb.kicad_pcb]
2025-12-16 Push finished 3d case
    [case.FCStd]
2025-12-16 Add updated pcb with corresponding gerber
    [odins-eye-pcb-B_Mask.gbs, odins-eye-pcb-B_Paste.gbp, odins-eye-pcb-B_Silkscreen.gbo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]
2025-12-16 Made small, final change to case
    [case.FCStd, odins-eye-pcb.kicad_pcb]
2025-12-17 Add small changes
    [case.FCStd]
2025-12-20 Small changes
    [case.FCStd, odins-eye-pcb.kicad_pcb]
2025-12-31 Update 3D case
    [case.FCStd, odins-eye-pcb.kicad_pcb]
2026-01-02 Changes to the 3D case
    [case.FCStd]
2026-01-11 Push STL files for the finished 3D case
    [case.FCStd, enclosure-base.stl, enclosure-cover.stl]
2026-01-20 Add PCB v1.5
    [odins-eye-pcb-B_Mask.gbs, odins-eye-pcb-B_Paste.gbp, odins-eye-pcb-B_SilkS.gbo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]
2026-03-01 Add STEP files
    [case-odins-eye-base.step, case-odins-eye-cover.step, case.FCStd]
2026-03-01 Clean pcb folder
    [odins-eye-pcb-B_Mask.gbs, odins-eye-pcb-B_Paste.gbp, odins-eye-pcb-B_SilkS.gbo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]
2026-03-03 Begin readme
    [case.FCStd]
2026-03-04 Continue work on README
    [bom.csv, odins-eye-pcb.kicad_pcb]
2026-05-03 Add speed detection code and update readme with finished project images
    [case.FCStd]
2026-05-13 Add image of the finished complete assembly to README
